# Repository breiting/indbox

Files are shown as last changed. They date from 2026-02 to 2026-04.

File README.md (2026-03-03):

# INDbox

_Interaction & Generative Design Interface_

🎛️ INDbox is an open-source physical computing interface designed for creative coding, generative design, and interactive media education.

It provides a standardized hardware input platform that allows students to explore sensor-based interaction systems without needing to build electronics from scratch.

The box acts as a bridge between the physical and digital world: tangible input is captured by a microcontroller and transmitted via USB to creative coding environments such as [Processing](https://processing.org), [p5.js](https://p5js.org), [TouchDesigner](https://derivative.ca/UserGuide/TouchDesigner), [Unity](https://unity.com), or [OpenFrameworks](https://openframeworks.cc).

<p align="center">
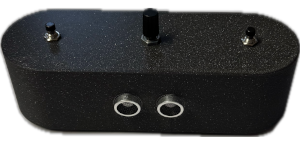
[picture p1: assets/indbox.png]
  
</p>

## 🧠 Concept

INDbox is **not a consumer product** but an educational interface and experimentation tool.

It enables students to:

- Understand input → transformation → output systems
- Design expressive mappings between sensors and visuals
- Prototype interactive installations quickly
- Work within a shared hardware standard
- Exchange code and ideas without hardware incompatibilities

## 🔧 Hardware Overview

Each INDbox contains:

- Microcontroller: ESP32 (USB-powered, Serial over USB)
- 2 × Push Buttons (discrete input)
- 1 × Rotary Potentiometer (continuous input)
- 1 × Ultrasonic Distance Sensors (spatial input)
- [Custom 3D-printed](/hardware/) enclosure
- Internal PCB / wiring harness

All sensor data is streamed via USB Serial to a host computer.

INDbox itself produces no visual output — all feedback happens in software.

## 📦 Open Source Hardware

All hardware files are available in this repository are open source.
You are free to modify, reproduce, and adapt the design.

## 🛠️ Assembly

Step-by-step [assembly guide](/docs/hardware.md):

## ⚡ Firmware Flashing

The firmware is written in Arduino (ESP32 core).

It reads all sensors and streams standardized as simple CSV data:

```
btn1,btn2,pot,dist
```

Firmware flashing instructions can be found in [flashing instructions](/docs/flashing.md)

Includes:

- Arduino IDE installation
- ESP32 board setup
- USB driver notes
- Upload instructions

## 🎓 Example Projects

The INDbox is part of an educational program taught by the author at [FH Joanneum](https://www.fh-joanneum.at) and will be used during the summer semester 2026.

After the course, students are encouraged to share and publish their projects in a separate repository dedicated to INDbox-based work.

## Processing 4 Integration

Please take a look at the [INDbox Processing Library](https://github.com/breiting/indbox-processing).

## Analyse Tool

There is a small Python test script which allows for showing or capturing live data. Have a look at [python](/python).

## 📜 License

Hardware and firmware are released under open-source licenses.

See LICENSE file for details.

## 🧩 Version

`INDbox v1`: Initial educational release.

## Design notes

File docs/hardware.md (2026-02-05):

# Hardware Overview

This document lists the hardware used in INDbox and provides the GPIO mapping between the ESP32 and the connected components.

## Bill of Materials (BOM)

### Core Electronics

- **Microcontroller:** ESP32 Dev Module / NodeMCU-style ESP32 (USB-powered, Serial over USB-C)
- **Ultrasonic distance sensor:** HC-SR04
- **Push buttons:** momentary push button / tactile switch (×2)
- **Potentiometer:** 10 kΩ linear rotary potentiometer

### Passive Components

- **Decoupling capacitors:** 100 nF ceramic (recommended near ESP32 3V3 and near each HC-SR04 VCC/GND)
- **Buffer capacitor:** 47 µF electrolytic (recommended on 5V rail near the ESP32 supply)
- **Voltage divider resistors (for HC-SR04 ECHO):**
  - 1 kΩ and 2 kΩ

> Note: HC-SR04 ECHO outputs 5V logic. The ESP32 GPIOs are 3.3V-only.
> Therefore ECHO must be level-shifted using a resistor divider.

### Connectors / Wiring

- 2.54 mm pin headers (or JST connectors) for:
  - Buttons
  - Potentiometer
  - HC-SR04 sensors
- Flexible wire (0.14–0.25 mm² is typical for internal wiring)

### Mechanical

- 3D-printed enclosure (see in `/hardware`)
- Mounting hardware (M3 screws, spacers, etc.)
- Perfboard

## Power

INDbox is powered via USB-C through the ESP32 board.

- **VIN / 5V:** used to power HC-SR04 sensors
- **3V3:** used for the potentiometer reference and ESP32 logic
- **GND:** common ground for all components

Recommended decoupling:

- 47 µF electrolytic between **5V and GND** (near ESP32 VIN)
- 100 nF ceramic between **3V3 and GND** (near ESP32 3V3 pin)
- 100 nF ceramic between **VCC and GND** near HC-SR04

## GPIO Mapping (INDbox)

This is the default pin mapping used by the firmware.

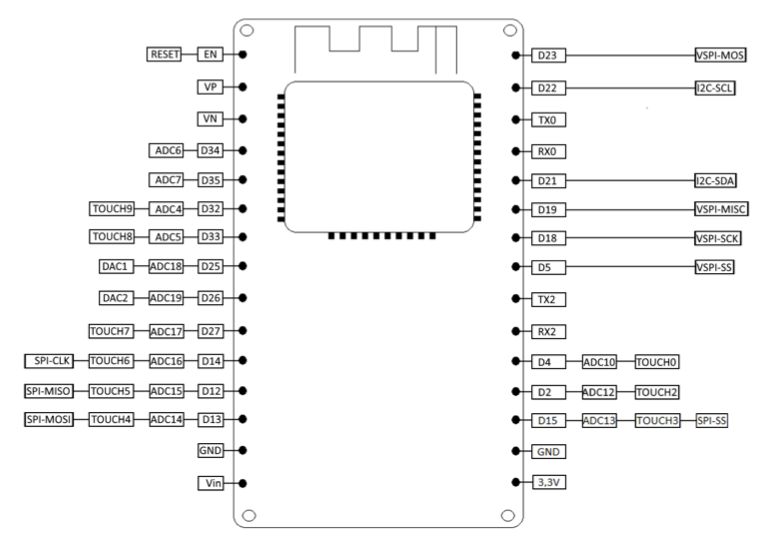
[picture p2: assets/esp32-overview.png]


### Inputs

| Component | Signal | ESP32 Pin Label | GPIO | Notes |
| --- | --- | --- | --- | --- |
| Button 1 | BTN1 | D32 | GPIO32 | Uses internal pull-up (active LOW) |
| Button 2 | BTN2 | D33 | GPIO33 | Uses internal pull-up (active LOW) |
| Potentiometer | Wiper  | D34 | GPIO34 | ADC input (0–4095). Connect pot ends to 3V3 and GND |
| HC-SR04 | TRIG | D25 | GPIO25 | Digital output |
| HC-SR04 | ECHO | D26 | GPIO26 | Digital input **via voltage divider** (5V → 3.3V) |

## Wiring Notes

### Buttons

Buttons are connected between the GPIO and GND.
The firmware enables `INPUT_PULLUP`, so the button reads:

- **released:** 1
- **pressed:** 0 (active LOW)

The firmware inverts this so the serial output uses:

- **released:** 0
- **pressed:** 1

### Potentiometer

The potentiometer is used as a voltage divider:

- One outer pin → **3V3**
- Middle pin (wiper) → **GPIO34 (ADC)**
- Other outer pin → **GND**

Do not connect the potentiometer to 5V, as the ESP32 ADC is 3.3V max.

### HC-SR04 Level Shifting (ECHO)

The HC-SR04 ECHO pin outputs a 5V logic signal. Since ESP32 GPIOs are 3.3V-only, the signal must be level-shifted using a resistor voltage divider.

Wiring:

- HC-SR04 ECHO → 1 kΩ → node → ESP32 ECHO GPIO
- Node → 2 kΩ → GND

This divider reduces the 5V signal to approximately 3.3V, which is safe for the ESP32 input.

> Important:
> Do not connect the ECHO pin directly to an ESP32 GPIO without level shifting.

## Firmware Data Format (Serial)

The firmware streams a continuous CSV line (default ~30 Hz):

```csv
btn1,btn2,pot,dist
```

Where:

- `btn1`, `btn2`: 0 or 1
- `pot`: 0..4095
- `dist`: distance in millimeters

See `/docs/flashing.md` for setup and `/firmware` for implementation details.

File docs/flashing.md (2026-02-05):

# Flashing Instructions

This guide explains how to install the required software, prepare your system for ESP32 development, and flash the INDbox v1 firmware onto the microcontroller.

The firmware is located in this repository under:

`/firmware/indbox_v1.ino`

## Install Arduino IDE

Before getting started you have to install the latest Arduino IDE on your system.
The software should be available for macOS, Linux, and Windows.
Download the package from [here](https://www.arduino.cc/en/software) or use your local package manager (e.g. Homebrew on macOS: `brew install arduino-ide`).

After installation, launch the Arduino IDE once to complete the initial setup.

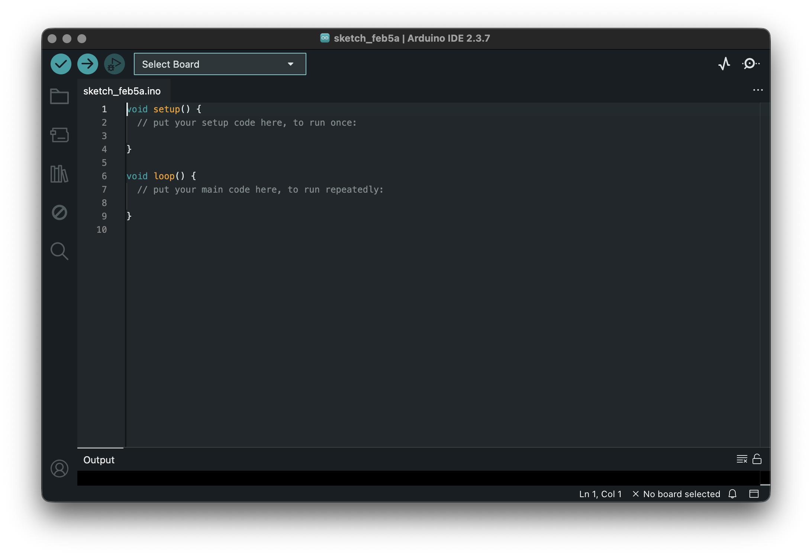
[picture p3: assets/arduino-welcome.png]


## Prepare ESP32 Board Support

The INDbox uses an ESP32 microcontroller by Joy-it ([NodeMCU ESP32-C](https://joy-it.net/de/products/SBC-NodeMCU-ESP32-C)). According to their [documentation](https://joy-it.net/files/files/Produkte/SBC-NodeMCU-ESP32-C/SBC-NodeMCU-ESP32-C_Manual-EN_2025-01-17.pdf), you have to install the proper packages for the Arduino IDE.

### Step 1 - Open Preferences

In Arduino IDE:

Arduino IDE → Settings / Preferences

Find the field:

“Additional Boards Manager URLs”

Add the following URL:

`https://dl.espressif.com/dl/package_esp32_index.json`

If other URLs already exist, separate them with commas.

Click OK to save.

**Important notice for Apple Silicon**:

Make sure that you have Rosetta installed properly!

```bash
softwareupdate --install-rosetta --agree-to-license
```

### Step 2 - Install ESP32 Boards

Go to:

Tools → Board → Boards Manager

Search for:

esp32

Install:

Select `esp32 by Espressif Systems`

This package includes:
• ESP32 toolchains
• USB flashing tools
• Board definitions

> HINT: Do not select the versions `3.x.x` (these one did not work for me!), but select the version `2.0.17`)

Installation may take several minutes due to package size.

### Step 3 - Connect INDbox Hardware

1.  Connect the INDbox to your computer via USB-C.
2.  The ESP32 should power on immediately.
3.  Your system will create a serial device.

Typical port names:

• macOS: /dev/cu.usbserial... or /dev/cu.SLAB_USBtoUART
• Windows: COM3, COM4, etc.
• Linux: /dev/ttyUSB0

### Step 4 - Select Board and Port

In Arduino IDE:

**Board**

Tools → Board → ESP32 Arduino → ESP32 Dev Module

(This matches the ESP32 NodeMCU-style board used in INDbox)

**Port**

Tools → Port → select the USB serial device

> Tip: Unplug the box, check the list, plug it in again — the new port is the correct one.

### Step 5 - Open Firmware

Open the firmware file:

File → Open
`./firmware/indbox_v1.ino`

The firmware reads all sensors and streams CSV data via USB Serial:

```csv
btn1,btn2,pot,dist1
```

### Step 6 - Compile and Upload

Click:

Upload → (Arrow icon)

The IDE will:

1. Compile the firmware
2. Connect to the ESP32
3. Flash the firmware

Typical console output:

Connecting...
Chip is ESP32
Uploading stub...
Writing at 0x00010000...
Hard resetting via RTS pin...

> HINT: If upload fails, press the BOOT button on the ESP32 while uploading (rarely needed on NodeMCU boards).

### Step 7 - Verify Operation

Open:

Tools → Serial Monitor

Set baud rate:

115200

You should see a continuous data stream similar to:

0,0,1234,250
1,0,1300,245

These are live sensor readings from the INDbox.

### Step 8 - Troubleshooting

No Port Appears

- Install USB drivers (CP210x / CH340 depending on board)
- Reconnect device

Upload Fails

- Check correct board selection
- Verify port
- Close Serial Monitor before uploading

No Sensor Data

- Check wiring
- Verify firmware version
- Ensure power via USB

### Step 9 - Firmware Updates

Future firmware releases will follow version naming:

`indbox_vx.ino`

To update:

1. Pull latest repository version
2. Open updated firmware
3. Upload again

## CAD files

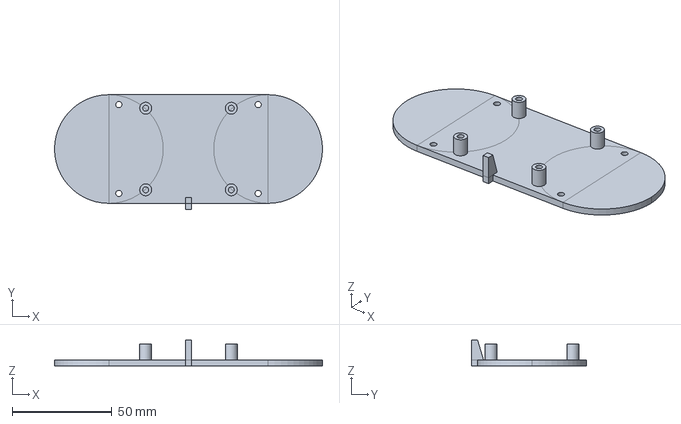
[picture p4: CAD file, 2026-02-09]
hardware/lid.step
134.6 x 57.6 x 13.0 mm

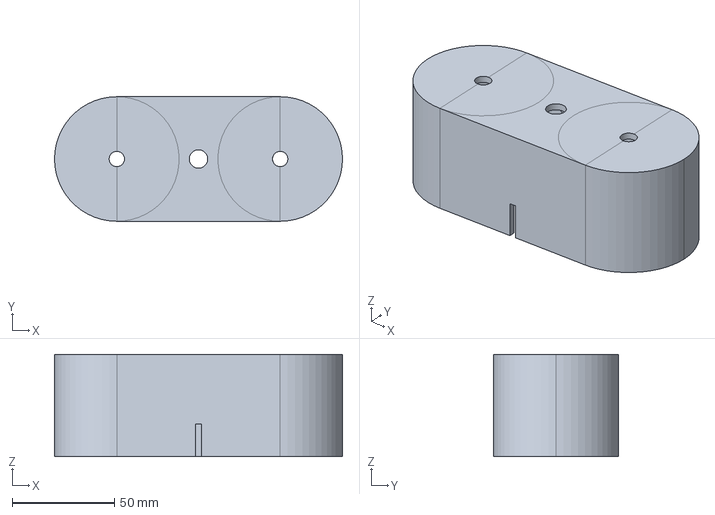
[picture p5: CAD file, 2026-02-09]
hardware/housing.step
141.0 x 61.0 x 50.0 mm

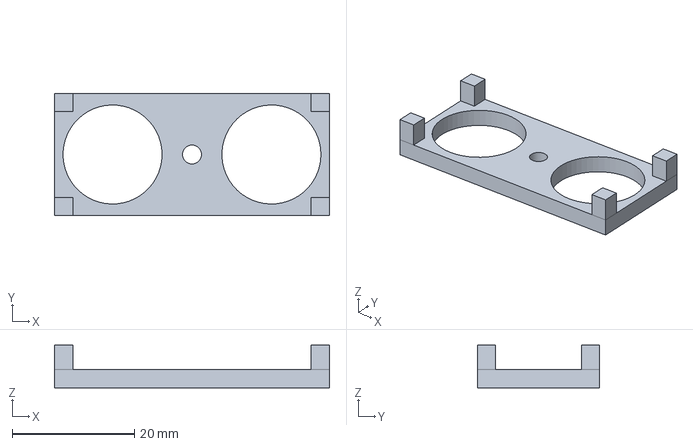
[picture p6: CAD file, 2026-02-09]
hardware/us_hc_sr04.step
45.0 x 20.0 x 7.00 mm

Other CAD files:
hardware/housing.stl
hardware/lid.stl
hardware/us_hc_sr04.stl

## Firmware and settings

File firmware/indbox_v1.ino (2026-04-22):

/*
  INDbox v1.1 – Firmware (2 Buttons, 1 Potentiometer, 1x HC-SR04)
  Revised version with controllable distance sensor update rate.

  Features:
    - CSV output: btn1,btn2,pot,dist_mm
    - DIST_ON  / DIST_OFF via serial
    - DIST_HZ <value> to change distance measurement rate
    - STATUS command for debugging
    - Distance stream remains filtered and never outputs -1

  Notes:
    - Potentiometer is still read raw for now.
    - Distance updates can be slowed down independently from the main output rate.
*/

#include <Arduino.h>

// ----------------------------
// Pin Mapping (INDbox v1.1)
// ----------------------------
static const int PIN_BTN1 = 33;
static const int PIN_BTN2 = 25;
static const int PIN_POT  = 35;

static const int PIN_US_TRIG = 26;
static const int PIN_US_ECHO = 32; // ECHO MUST be level-shifted to 3.3V!

// ----------------------------
// Serial / Timing
// ----------------------------
static const uint32_t SERIAL_BAUD = 115200;
static const uint32_t OUTPUT_INTERVAL_MS = 33; // ~30 Hz CSV output

// ----------------------------
// Ultrasonic constants
// ----------------------------
static const uint32_t US_TRIG_SETTLE_US     = 2;
static const uint32_t US_TRIG_PULSE_US      = 10;
static const uint32_t US_ECHO_TIMEOUT_US    = 30000;  // 30 ms
static const float    SOUND_SPEED_MM_PER_US = 0.343f;

static const long DIST_INVALID = -1;

// ----------------------------
// Distance filtering parameters
// ----------------------------
static const long  DIST_MIN_MM = 50;
static const long  DIST_MAX_MM = 2000;

static const float DIST_EMA_ALPHA = 0.25f;

static const long MAX_STEP_PER_SAMPLE_MM = 80;

// ----------------------------
// Distance runtime settings
// ----------------------------
static bool distanceEnableSlew = false;
static bool  distanceEnabled = true;
static float distanceHz = 10.0f;  // default distance measurement frequency
static uint32_t distanceIntervalMs = 100; // derived from Hz

// ----------------------------
// Distance filter state
// ----------------------------
static bool  hasValidDistance = false;
static long  lastGoodMm = 0;
static float distFiltered = 0.0f;

// ----------------------------
// Helper: update interval from Hz
// ----------------------------
void setDistanceHz(float hz) {
  if (hz < 0.5f) hz = 0.5f;
  if (hz > 30.0f) hz = 30.0f;

  distanceHz = hz;
  distanceIntervalMs = (uint32_t)(1000.0f / distanceHz + 0.5f);
  if (distanceIntervalMs < 1) distanceIntervalMs = 1;
}

// ----------------------------
// Ultrasonic raw measurement
// ----------------------------
long readUltrasonicMillimetersRaw() {
  digitalWrite(PIN_US_TRIG, LOW);
  delayMicroseconds(US_TRIG_SETTLE_US);

  digitalWrite(PIN_US_TRIG, HIGH);
  delayMicroseconds(US_TRIG_PULSE_US);
  digitalWrite(PIN_US_TRIG, LOW);

  const uint32_t duration_us = pulseIn(PIN_US_ECHO, HIGH, US_ECHO_TIMEOUT_US);
  if (duration_us == 0) {
    return DIST_INVALID;
  }

  const float mm = (duration_us * SOUND_SPEED_MM_PER_US) * 0.5f;
  return (long)(mm + 0.5f);
}

bool isDistanceValid(long mm) {
  return (mm >= DIST_MIN_MM && mm <= DIST_MAX_MM);
}

long clampStep(long current, long target, long maxStep) {
  long delta = target - current;
  if (delta >  maxStep) return current + maxStep;
  if (delta < -maxStep) return current - maxStep;
  return target;
}

// ----------------------------
// Serial command handling
// ----------------------------
void printStatus() {
  Serial.print("# DIST=");
  Serial.print(distanceEnableSlew ? "ON" : "OFF");
  Serial.print(distanceEnabled ? "ON" : "OFF");
  Serial.print(" DIST_HZ=");
  Serial.print(distanceHz, 2);
  Serial.print(" DIST_INTERVAL_MS=");
  Serial.print(distanceIntervalMs);
  Serial.print(" LAST_GOOD_MM=");
  Serial.print(lastGoodMm);
  Serial.print(" FILTERED_MM=");
  Serial.println((long)(distFiltered + 0.5f));
}

void handleSerialCommands() {
  while (Serial.available() > 0) {
    String cmd = Serial.readStringUntil('\n');
    cmd.trim();

    if (cmd.length() == 0) return;

    if (cmd.equalsIgnoreCase("DIST_ON")) {
      distanceEnabled = true;
      Serial.println("# DIST_ON");
    }
    else if (cmd.equalsIgnoreCase("DIST_OFF")) {
      distanceEnabled = false;
      Serial.println("# DIST_OFF");
    }
    else if (cmd.equalsIgnoreCase("DIST_SLEW_ON")) {
      distanceEnableSlew = true;
      Serial.println("# DIST_SLEW_ON");
    }
    else if (cmd.equalsIgnoreCase("DIST_SLEW_OFF")) {
      distanceEnableSlew = false;
      Serial.println("# DIST_SLEW_OFF");
    }
    else if (cmd.equalsIgnoreCase("STATUS")) {
      printStatus();
    }
    else if (cmd.startsWith("DIST_HZ") || cmd.startsWith("dist_hz")) {
      int spaceIndex = cmd.indexOf(' ');
      if (spaceIndex > 0) {
        String valueStr = cmd.substring(spaceIndex + 1);
        valueStr.trim();
        float hz = valueStr.toFloat();

        if (hz > 0.0f) {
          setDistanceHz(hz);
          Serial.print("# DIST_HZ=");
          Serial.println(distanceHz, 2);
        } else {
          Serial.println("# ERR invalid DIST_HZ value");
        }
      } else {
        Serial.println("# ERR usage: DIST_HZ 10");
      }
    }
    else {
      Serial.print("# ERR unknown command: ");
      Serial.println(cmd);
    }
  }
}

// ----------------------------
// Setup
// ----------------------------
void setup() {
  Serial.begin(SERIAL_BAUD);

  pinMode(PIN_BTN1, INPUT_PULLUP);
  pinMode(PIN_BTN2, INPUT_PULLUP);
  pinMode(PIN_POT, INPUT);

  pinMode(PIN_US_TRIG, OUTPUT);
  pinMode(PIN_US_ECHO, INPUT);

  setDistanceHz(distanceHz);

  Serial.println("btn1,btn2,pot,dist_mm");
  printStatus();
}

// ----------------------------
// Main Loop
// ----------------------------
void loop() {
  static uint32_t lastOutputMs = 0;
  static uint32_t lastDistanceMs = 0;

  handleSerialCommands();

  const uint32_t nowMs = millis();

  // ------------------------
  // Distance update (independent timing)
  // ------------------------
  if (distanceEnabled && (nowMs - lastDistanceMs >= distanceIntervalMs)) {
    lastDistanceMs = nowMs;

    const long rawMm = readUltrasonicMillimetersRaw();

    if (isDistanceValid(rawMm)) {
      lastGoodMm = rawMm;

      if (!hasValidDistance) {
        distFiltered = (float)lastGoodMm;
        hasValidDistance = true;
      }
    }

    if (hasValidDistance) {
      long targetMm = lastGoodMm;

      if (distanceEnableSlew) {
        long currentMm = (long)(distFiltered + 0.5f);
        targetMm = clampStep(currentMm, targetMm, MAX_STEP_PER_SAMPLE_MM);
      }

      distFiltered = distFiltered + DIST_EMA_ALPHA * ((float)targetMm - distFiltered);
    }
  }

  // ------------------------
  // Main CSV output (~30 Hz)
  // ------------------------
  if (nowMs - lastOutputMs < OUTPUT_INTERVAL_MS) return;
  lastOutputMs = nowMs;

  const int btn1 = (digitalRead(PIN_BTN1) == LOW) ? 1 : 0;
  const int btn2 = (digitalRead(PIN_BTN2) == LOW) ? 1 : 0;
  const int pot  = analogRead(PIN_POT);

  const long outMm = hasValidDistance ? (long)(distFiltered + 0.5f) : 0;

  Serial.print(btn1);
  Serial.print(',');
  Serial.print(btn2);
  Serial.print(',');
  Serial.print(pot);
  Serial.print(',');
  Serial.println(outMm);
}

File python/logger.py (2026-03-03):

import argparse
import csv
import time
from collections import deque

import serial
import serial.tools.list_ports


def list_ports():
    ports = list(serial.tools.list_ports.comports())
    if not ports:
        print("No serial ports found.")
        return
    for p in ports:
        print(f"- {p.device} | {p.description}")


def pick_port(hint: str | None) -> str:
    ports = list(serial.tools.list_ports.comports())
    if not ports:
        raise SystemExit("No serial ports found. Is the INDbox connected?")

    if hint:
        h = hint.lower()
        for p in ports:
            if h in (p.device or "").lower() or h in (p.description or "").lower():
                return p.device

    # Heuristic: prefer real USB-UART and prefer 'cu.' on macOS
    def score(p):
        dev = (p.device or "").lower()
        desc = (p.description or "").lower()
        s = 0
        if "usbserial" in dev or "usbmodem" in dev:
            s += 50
        if (
            "cp210" in desc
            or "silabs" in desc
            or "ch340" in desc
            or "usb to uart" in desc
        ):
            s += 40
        if dev.startswith("cu."):
            s += 10
        if dev.startswith("tty."):
            s += 2
        if "debug-console" in dev or "debug-console" in desc:
            s -= 100
        return s

    ports.sort(key=score, reverse=True)
    return ports[0].device


def parse_line(line: str):
    # expected: b1,b2,pot,dist
    parts = [p.strip() for p in line.strip().split(",")]
    if len(parts) < 4:
        return None
    try:
        b1 = 1 if int(parts[0]) != 0 else 0
        b2 = 1 if int(parts[1]) != 0 else 0
        pot = int(parts[2])
        dist = float(parts[3])
        return b1, b2, pot, dist
    except Exception:
        return None


def open_serial(port: str, baud: int):
    ser = serial.Serial(port=port, baudrate=baud, timeout=0.2)
    # flush junk
    ser.reset_input_buffer()
    return ser


def run_record_csv(ser, out_path: str, duration_s: float | None):
    t0 = time.time()
    ok = bad = 0

    with open(out_path, "w", newline="") as f:
        writer = csv.writer(f)
        writer.writerow(["t_sec", "b1", "b2", "pot", "dist", "raw"])

        print(f"Recording to {out_path} ...")
        print(
            "Stop with Ctrl+C" if duration_s is None else f"Duration: {duration_s:.1f}s"
        )

        try:
            while True:
                if duration_s is not None and (time.time() - t0) >= duration_s:
                    break

                raw = ser.readline().decode("utf-8", errors="ignore").strip()
                if not raw:
                    continue
                if raw.startswith("b1") or raw.startswith("#"):
                    continue

                parsed = parse_line(raw)
                if parsed is None:
                    bad += 1
                    continue

                ok += 1
                b1, b2, pot, dist = parsed
                t = time.time() - t0
                writer.writerow([f"{t:.4f}", b1, b2, pot, f"{dist:.4f}", raw])

        except KeyboardInterrupt:
            pass

    print(f"Done. ok={ok}, bad={bad}")


def run_live_plot(ser, window_s: float, sample_hz_hint: float):
    import matplotlib.pyplot as plt

    # rolling buffers
    t_buf = deque()
    pot_buf = deque()
    dist_buf = deque()
    b1_buf = deque()
    b2_buf = deque()

    t0 = time.time()
    ok = bad = 0

    plt.ion()
    _, ax = plt.subplots()
    (pot_line,) = ax.plot([], [], label="pot (raw)")
    (dist_line,) = ax.plot([], [], label="dist")
    ax.set_xlabel("time (s)")
    ax.set_ylabel("value")
    ax.legend(loc="upper right")

    # update interval
    redraw_every = max(1, int(sample_hz_hint / 10))  # ~10 fps redraw
    n = 0

    print("Live plot running. Stop with Ctrl+C")
    try:
        while True:
            raw = ser.readline().decode("utf-8", errors="ignore").strip()
            if not raw:
                continue
            if raw.startswith("b1") or raw.startswith("#"):
                continue

            parsed = parse_line(raw)
            if parsed is None:
                bad += 1
                continue

            ok += 1
            b1, b2, pot, dist = parsed
            t = time.time() - t0

            t_buf.append(t)
            pot_buf.append(pot)
            dist_buf.append(dist)
            b1_buf.append(b1)
            b2_buf.append(b2)

            # drop old samples outside window
            while t_buf and (t - t_buf[0]) > window_s:
                t_buf.popleft()
                pot_buf.popleft()
                dist_buf.popleft()
                b1_buf.popleft()
                b2_buf.popleft()

            n += 1
            if n % redraw_every == 0:
                pot_line.set_data(list(t_buf), list(pot_buf))
                dist_line.set_data(list(t_buf), list(dist_buf))

                ax.relim()
                ax.autoscale_view()
                ax.set_title(f"INDbox live (ok={ok}, bad={bad})  |  last='{raw[:40]}'")
                plt.pause(0.001)

    except KeyboardInterrupt:
        print(f"\nStopped. ok={ok}, bad={bad}")


def main():
    ap = argparse.ArgumentParser(
        description="INDbox stability logger: live plot or record CSV"
    )
    ap.add_argument("--list", action="store_true", help="List serial ports and exit")
    ap.add_argument(
        "--port",
        default=None,
        help="Serial port (e.g. /dev/cu.usbserial-0001). If omitted, auto-pick.",
    )
    ap.add_argument(
        "--hint",
        default=None,
        help="Substring to match port device/description (e.g. usbserial, CP2102)",
    )
    ap.add_argument(
        "--baud", type=int, default=115200, help="Baud rate (default 115200)"
    )
    ap.add_argument(
        "--mode",
        choices=["live", "csv"],
        default="live",
        help="Mode: live plot or CSV record",
    )
    ap.add_argument(
        "--out", default="indbox_log.csv", help="CSV output path (mode=csv)"
    )
    ap.add_argument(
        "--duration",
        type=float,
        default=None,
        help="Record duration in seconds (mode=csv). Default: until Ctrl+C",
    )
    ap.add_argument(
        "--window",
        type=float,
        default=10.0,
        help="Live plot window in seconds (mode=live)",
    )
    ap.add_argument(
        "--hz",
        type=float,
        default=30.0,
        help="Expected sample rate (for plotting refresh only)",
    )
    args = ap.parse_args()

    if args.list:
        list_ports()
        return

    port = args.port or pick_port(args.hint)
    print(f"Using port: {port} @ {args.baud}")
    ser = open_serial(port, args.baud)

    try:
        if args.mode == "csv":
            run_record_csv(ser, args.out, args.duration)
        else:
            run_live_plot(ser, args.window, args.hz)
    finally:
        try:
            ser.close()
        except Exception:
            pass


if __name__ == "__main__":
    main()
